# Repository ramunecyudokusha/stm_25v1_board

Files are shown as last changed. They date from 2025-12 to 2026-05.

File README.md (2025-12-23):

# stm_25v1_board
stm32f446が乗った基板を開発する
# 開発品(随時更新)





# 目次
基板の概要
各基板の機能
ピン割り当て
#

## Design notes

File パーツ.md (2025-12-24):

#  部品表
##  抵抗
https://www.digikey.jp/ja/products/detail/rohm-semiconductor/KTR03EZPF75R0/4051692
75Ωパッケージ0603
https://www.digikey.jp/ja/products/detail/rohm-semiconductor/KTR10EZPF1200/4051743
120Ωパッケージ0805
https://www.zaikostore.com/zaikostore/stockDetail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ッケージ0805
5.1kΩパッケージ1206

##  コンデンサ
https://akizukidenshi.com/catalog/g/g116143/
0.1ufパッケージ0603
https://akizukidenshi.com/catalog/g/g112928/ 
チップコンデンサ小さいver(0.1uf)0201
https://akizukidenshi.com/catalog/g/g116077/
2.2ufパッケージ0603
https://eleshop.jp/shop/g/g3346000/?srsltid=AfmBOoroI3kPq9OWnBu_ChpYzPOFjAbqED8pnnSZSS_fm8IS80MVJ_uQ
0.39ufパッケージ0603  秋月電子通商での取り扱いなし
https://akizukidenshi.com/catalog/g/g113822/
4.7ufパッケージ0805
https://akizukidenshi.com/catalog/g/g116994/
1uf パッケージ0603
https://akizukidenshi.com/catalog/g/g108240/
レギュレータ平滑用電解コンデンサ(22uf)パッケージ0805 
##  IC
STM32F446re

1A.3.3V固定出力レギュレーター
https://www.rohm.co.jp/products/power-management/linear-regulators/single-output-ldo-regulators/bd33fc0fp-product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
BD33FC0FP-E2
1AMAX 3.3Vout
1A,5v固定出力レギュレーター
https://www.rohm.co.jp/products/power-management/linear-regulators/single-output-ldo-regulators/bd50fc0fp-product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
今回は使わなかった
canモジュール
https://www.rohm.co.jp/products/interface/can-transceiver/bd41044fj-c-product
mcp2561 or BD41044FJ-C(mcp2561互換)

## その他
https://akizukidenshi.com/catalog/r/rferrite2/
フェライトビーズ(選定途中)パッケージ0603
https://www.rohm.co.jp/products/led/chip-leds-mono-color-type/standard/sml-e12p8w-product#productDetail
LED(緑) 通信確認用パッケージ1608
https://www.rohm.co.jp/products/led/chip-leds-mono-color-type/standard/sml-e12uw-product
通電確認用LED赤 パッケージ1608
LED秋月LEDページ https://akizukidenshi.com/catalog/goods/search.aspx?search=x&keyword=SML&search=search

https://www.rohm.co.jp/products/diodes/schottky-barrier-diodes/ultra-low-vf/rb161qs-40-product#productDetail
TVSダイオード パッケージ1006
https://akizukidenshi.com/catalog/g/g115707/
can用抵抗切り替えスライドスイッチ

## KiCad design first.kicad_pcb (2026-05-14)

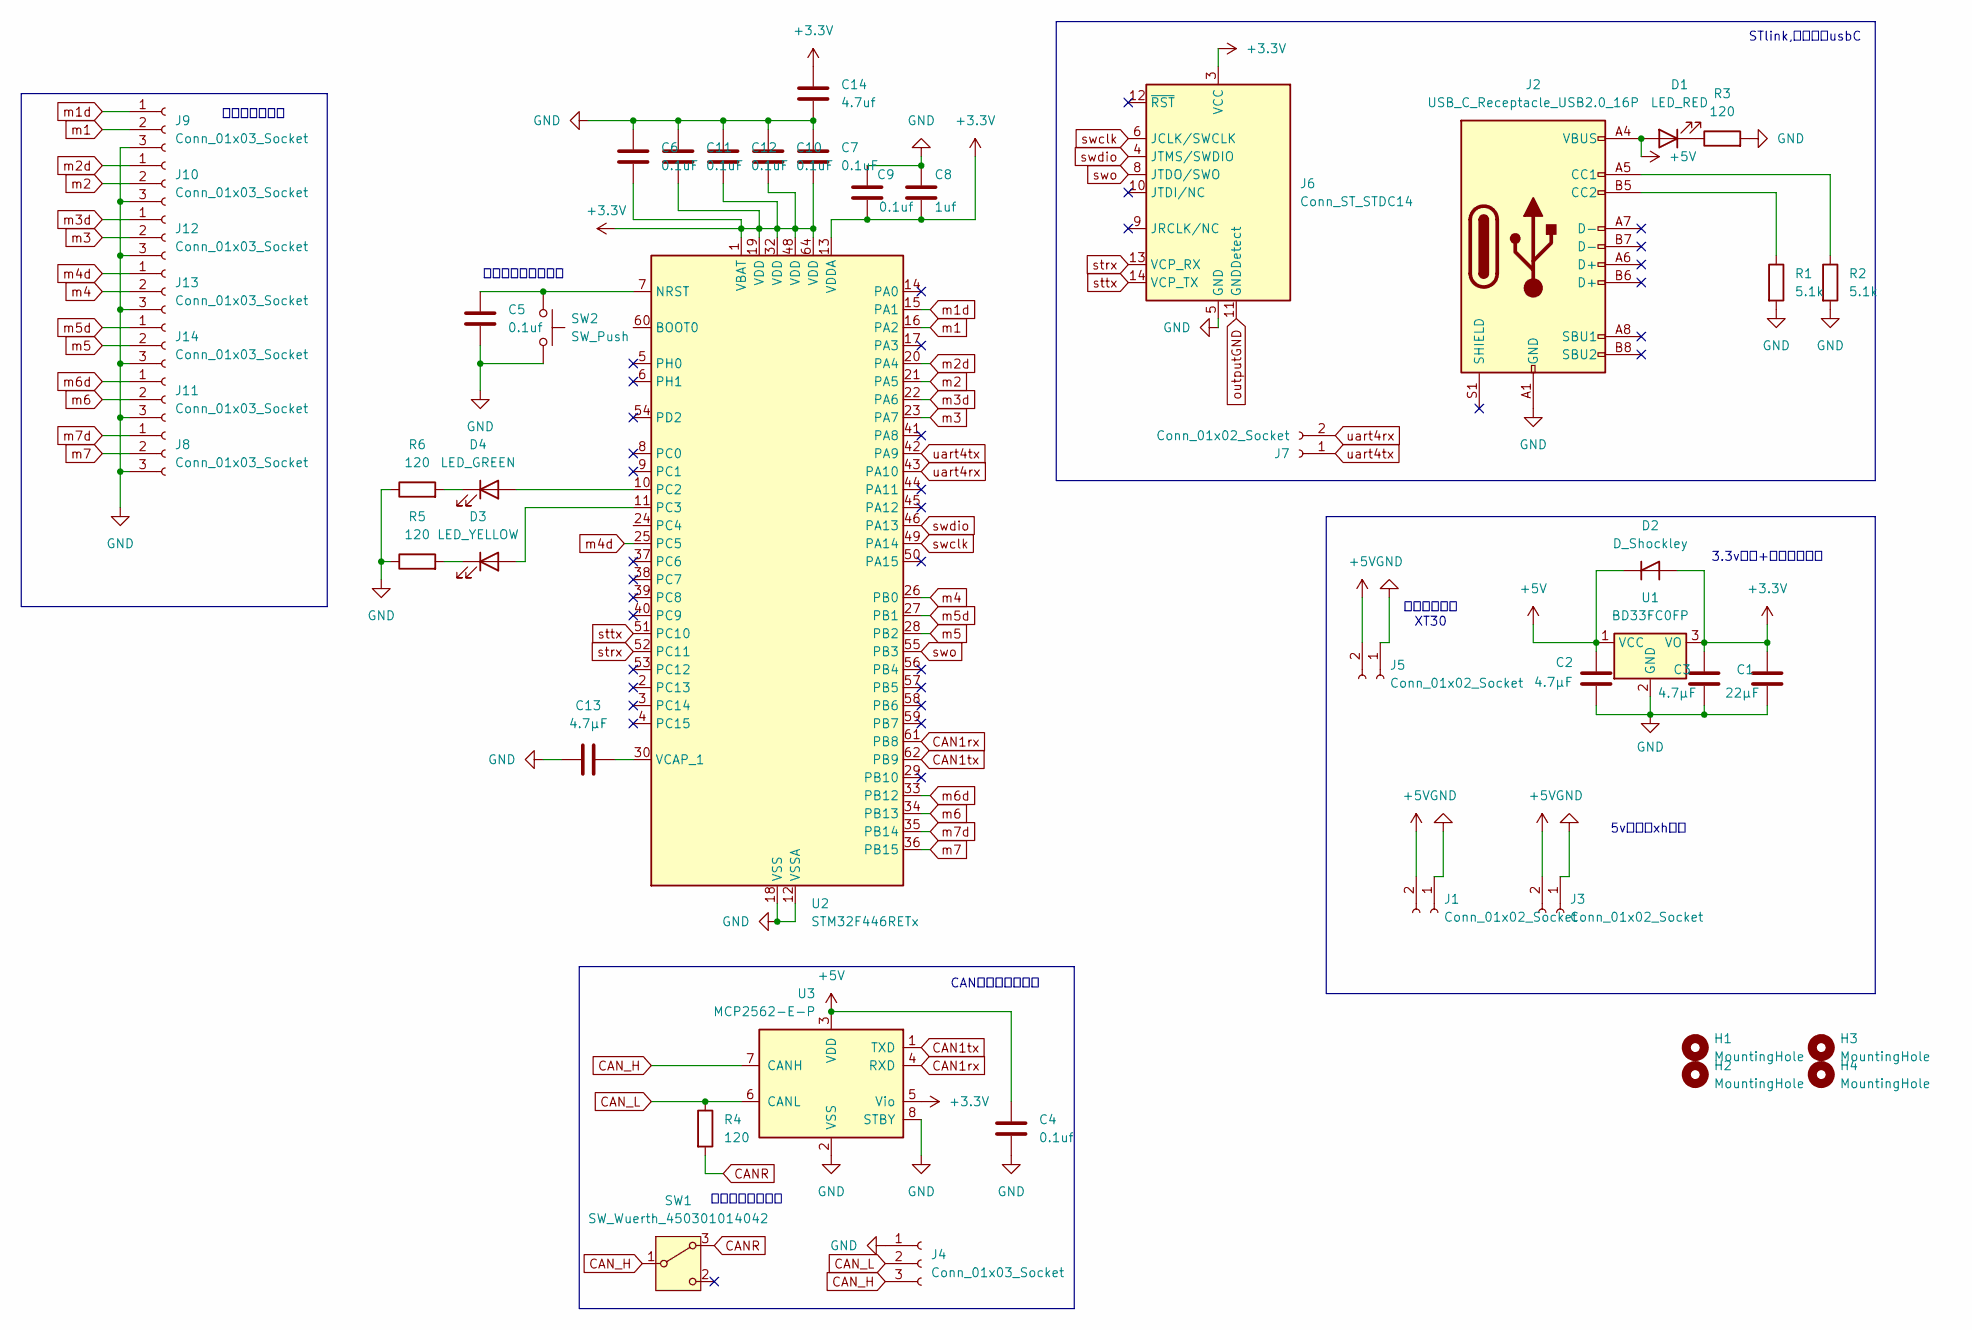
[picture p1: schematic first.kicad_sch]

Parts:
C1: 22μF; C_0805_2012Metric_Pad1.18x1.45mm_HandSolder
C2, C3: 4.7μF; C_0805_2012Metric_Pad1.18x1.45mm_HandSolder
C4, C5: 0.1uf; C_0603_1608Metric_Pad1.08x0.95mm_HandSolder
C6, C7, C10, C11, C12: 0.1uF; C_0402_1005Metric_Pad0.74x0.62mm_HandSolder
C8: 1uf; C_0603_1608Metric_Pad1.08x0.95mm_HandSolder
C9: 0.1uf; C_0402_1005Metric_Pad0.74x0.62mm_HandSolder
C13: 4.7μF; C_0603_1608Metric_Pad1.08x0.95mm_HandSolder
C14: 4.7uf; C_0603_1608Metric_Pad1.08x0.95mm_HandSolder
D1: LED_RED; D_0805_2012Metric_Pad1.15x1.40mm_HandSolder
D2: D_Shockley; D_SOD-323_HandSoldering
D3: LED_YELLOW; D_0805_2012Metric_Pad1.15x1.40mm_HandSolder
D4: LED_GREEN; D_0805_2012Metric_Pad1.15x1.40mm_HandSolder
H1, H2, H3, H4: MountingHole; MountingHole_3.2mm_M3
J1, J3, J7: Conn_01x02_Socket; JST_XH_S2B-XH-A-1_1x02_P2.50mm_Horizontal
J2: USB_C_Receptacle_USB2.0_16P; USB_C_Receptacle_GCT_USB4105-xx-A_16P_TopMnt_Horizontal
J4, J8, J9, J10, J11, J12, J13, J14: Conn_01x03_Socket; JST_XH_S3B-XH-A-1_1x03_P2.50mm_Horizontal
J5: Conn_01x02_Socket; AMASS_XT30PW-F_1x02_P2.50mm_Horizontal
J6: Conn_ST_STDC14; PinHeader_2x07_P1.27mm_Vertical
R1, R2: 5.1k; R_0603_1608Metric_Pad0.98x0.95mm_HandSolder
R3, R4, R5, R6: 120; R_0603_1608Metric_Pad0.98x0.95mm_HandSolder
SW1: SW_Wuerth_450301014042; SW_Slide-03_Wuerth-WS-SLTV_10x2.5x6.4_P2.54mm
SW2: SW_Push; SW_PUSH_6mm
U1: BD33FC0FP; TO-252-2
U2: STM32F446RETx; LQFP-64_10x10mm_P0.5mm
U3: MCP2562-E-P; DIP-8_W7.62mm

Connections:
+3.3V: C1.1, C3.1, C6.1, C7.1, C8.2, C9.2, C10.1, C11.1, C12.1, C14.1, D2.2 (A), J6.3 (VCC), U1.3 (VO), U2.1 (VBAT), U2.13 (VDDA), U2.19 (VDD), U2.32 (VDD), U2.48 (VDD), U2.64 (VDD), U3.5 (Vio)
+5V: C2.1, C4.1, D1.2 (A), D2.1 (K), J1.2, J2.A4 (VBUS), J2.A9 (VBUS), J2.B4 (VBUS), J2.B9 (VBUS), J3.2, J5.2, U1.1 (VCC), U3.3 (VDD)
CAN1rx: U2.61 (PB8), U3.4 (RXD)
CAN1tx: U2.62 (PB9), U3.1 (TXD)
CANR: R4.2, SW1.3 (A)
CAN_H: J4.3, SW1.1 (B), U3.7 (CANH)
CAN_L: J4.2, R4.1, U3.6 (CANL)
GND: C1.2, C2.2, C3.2, C4.2, C5.2, C6.2, C7.2, C8.1, C9.1, C10.2, C11.2, C12.2, C13.1, C14.2, J1.1, J2.A1 (GND), J2.A12 (GND), J2.B1 (GND), J2.B12 (GND), J3.1, J4.1, J5.1, J6.5 (GND), J6.7 (GND), J8.3, J9.3, J10.3, J11.3, J12.3, J13.3, J14.3, R1.2, R2.2, R3.2, R5.1, R6.1, SW2.2, U1.2 (GND), U2.12 (VSSA), U2.18 (VSS), U2.31 (VSS), U2.47 (VSS), U2.63 (VSS), U3.2 (VSS), U3.8 (STBY)
unnamed: D1.1 (K), R3.1
unnamed: D3.2 (A), U2.11 (PC3)
unnamed: D3.1 (K), R5.2
unnamed: D4.2 (A), U2.10 (PC2)
unnamed: D4.1 (K), R6.2
unnamed: J2.A5 (CC1), R2.1
unnamed: J2.B5 (CC2), R1.1
unnamed: C5.1, SW2.1, U2.7 (NRST)
unnamed: C13.2, U2.30 (VCAP_1)
m1: J9.2, U2.16 (PA2)
m1d: J9.1, U2.15 (PA1)
m2: J10.2, U2.21 (PA5)
m2d: J10.1, U2.20 (PA4)
m3: J12.2, U2.23 (PA7)
m3d: J12.1, U2.22 (PA6)
m4: J13.2, U2.26 (PB0)
m4d: J13.1, U2.25 (PC5)
m5: J14.2, U2.28 (PB2)
m5d: J14.1, U2.27 (PB1)
m6: J11.2, U2.34 (PB13)
m6d: J11.1, U2.33 (PB12)
m7: J8.2, U2.36 (PB15)
m7d: J8.1, U2.35 (PB14)
outputGND: J6.11 (GNDDetect)
strx: J6.13 (VCP_RX), U2.52 (PC11)
sttx: J6.14 (VCP_TX), U2.51 (PC10)
swclk: J6.6 (JCLK/SWCLK), U2.49 (PA14)
swdio: J6.4 (JTMS/SWDIO), U2.46 (PA13)
swo: J6.8 (JTDO/SWO), U2.55 (PB3)
uart4rx: J7.2, U2.43 (PA10)
uart4tx: J7.1, U2.42 (PA9)

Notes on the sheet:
終端抵抗オンオフ
電源コネクタ XT30
3.3v変圧+逆流防止回路
5v供給用xh端子
STlink,電源供給usbC
CANトランシーバー
モーター用出力
リセット用スイッチ

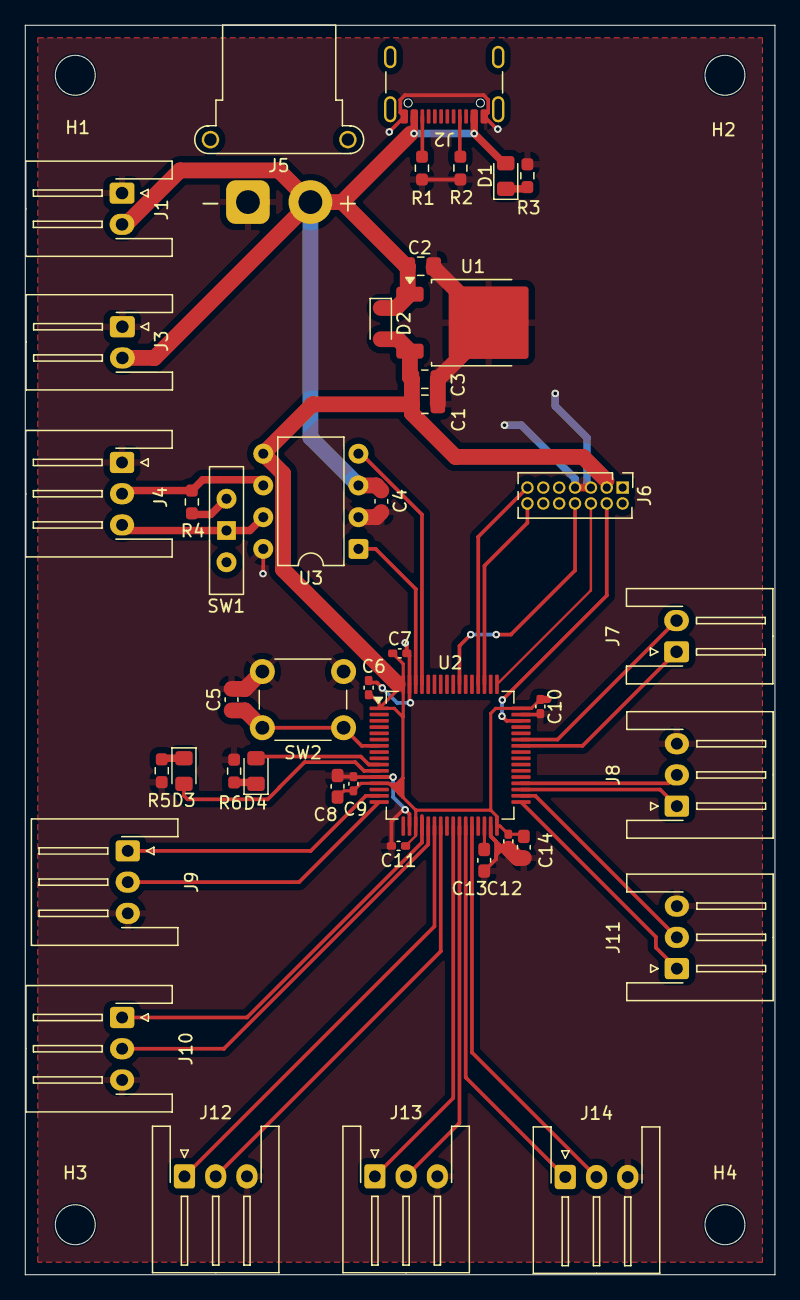
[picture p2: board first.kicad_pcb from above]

Board: 2 copper layers, 60.0 x 100.0 mm, 47 parts (0 on the bottom side), 38 nets.

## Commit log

2025-12-21 Update README.md
    描こうと思ったけどねむい
2025-12-22 Create パーツ.md
    create page and writing
    unfinished
2025-12-24 Update パーツ.md
    通販URLの追加。各部品との結び付け未完了
2026-05-14 完成品をmainに移す
    [first.kicad_pcb, first.kicad_sch]
